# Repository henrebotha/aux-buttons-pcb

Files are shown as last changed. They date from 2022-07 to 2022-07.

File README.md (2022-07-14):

# Fightstick aux buttons PCB

This is a design for a small PCB containing three tactile pushbutton switches. It's intended for use as menu buttons in a fightstick, but can be used for any number of things. A 4-pin JST-PH connector can be used to connect this to other circuits. It occupies a footprint of about 8×50 mm on the control panel, but the physical size is 10×60 mm (more like 10×70 mm if you account for connecting something to the JST).

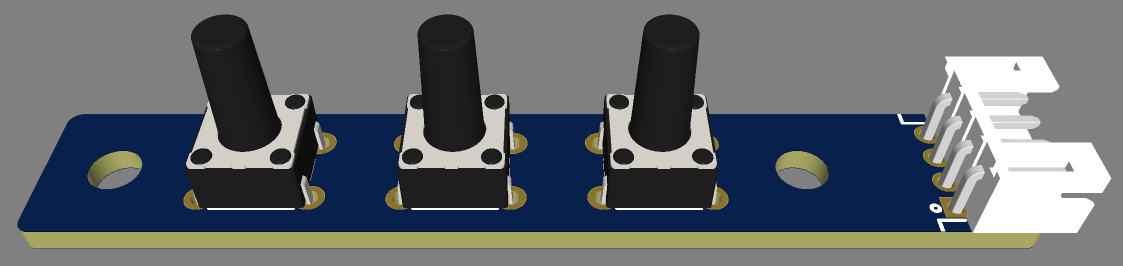
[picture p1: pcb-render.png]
A render of the PCB


The buttons and connections are labeled on the bottom side of the PCB. The buttons are connected to a common ground, marked `G` next to the appropriate pin on the JST.

The PCB is designed to mount under the control panel on a pair of 6 mm spacers (it has two 3.2 mm holes that can accept an M3 thread). The switches are roughly 9 mm tall, so mounting the PCB this way will allow the switches to protrude from the top of a control panel that is less than 3 mm thick. The mounting holes and switches are all in one line. The distance between the mounting holes and switches is 9 mm, and the distance between switches is 12 mm (all these dimensions are centre to centre). The switches need a hole with a diameter of at least 4.5 mm. See the diagram below for recommended panel cutouts.

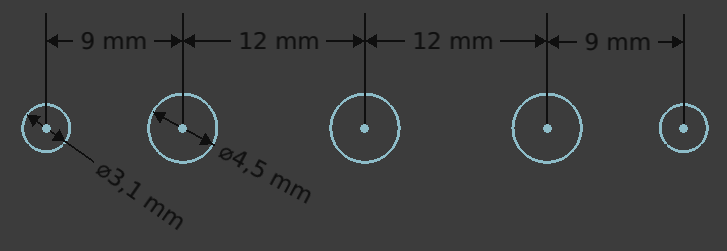
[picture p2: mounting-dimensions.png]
Diagram indicating panel mounting cutout dimensions


The design assumes the use of Omron B3F-1070 switches, but any pushbutton in the common 6×6 mm footprint should work, assuming it's tall enough. (The JST-PH connector sits on the same side of the PCB as the switches, which is why spacers & tall buttons are necessary.)

This project was designed using EasyEDA.

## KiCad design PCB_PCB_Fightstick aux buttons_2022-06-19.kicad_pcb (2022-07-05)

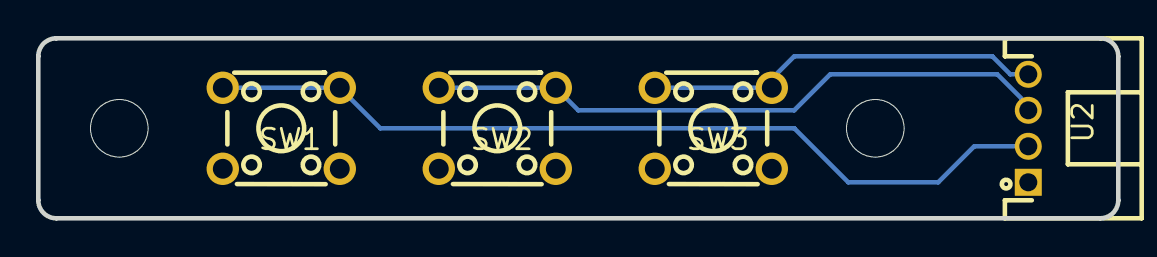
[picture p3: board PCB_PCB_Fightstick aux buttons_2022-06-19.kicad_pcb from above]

Board: 2 copper layers, 60.0 x 10.0 mm, 4 parts (0 on the bottom side), 4 nets.

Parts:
SW1, SW2, SW3: B3F-1070; SW-TH_4P-L6.2-W6.2-P4.50-LS6.5
U2: S4B-PH-K-S-(LF)(SN); CONN-TH_4P-P2.00_S4B-PH-K-S-LF-SN

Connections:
GND: SW1.3, SW1.4, SW2.3, SW2.4, SW3.3, SW3.4, U2.1
SW1_2: SW1.1, SW1.2, U2.2
SW2_2: SW2.1, SW2.2, U2.3
SW3_2: SW3.1, SW3.2, U2.4
